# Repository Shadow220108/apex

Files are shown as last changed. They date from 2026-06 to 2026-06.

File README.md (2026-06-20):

<h1 align="center">
  <br>
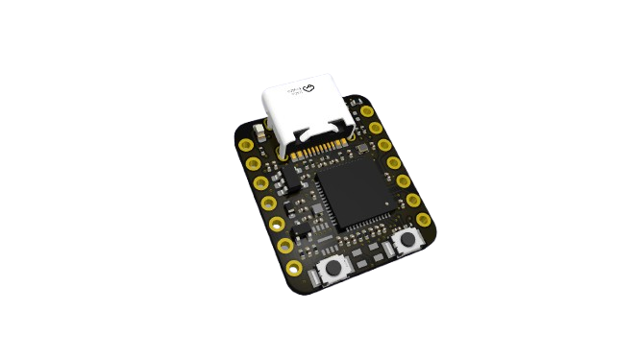
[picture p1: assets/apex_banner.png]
apex banner
  

  <br>
  Apex
  <br>
</h1>
<h3 align="center">
A fully open-sourced compact devboard inspired by the Seed Studio Xiao RP2040 with extra features such as LiPo support 
</h3>

| Front Render | Back Render | 
| --- | --- |
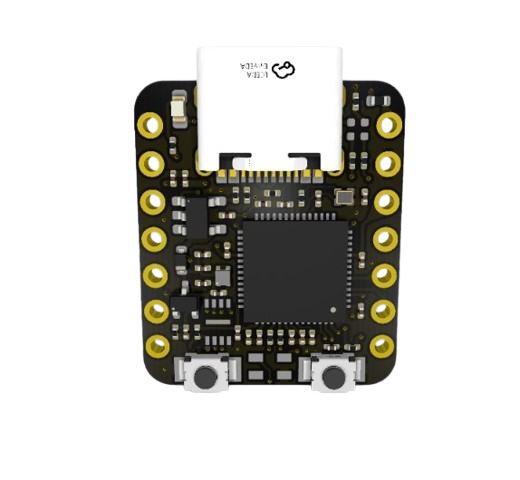
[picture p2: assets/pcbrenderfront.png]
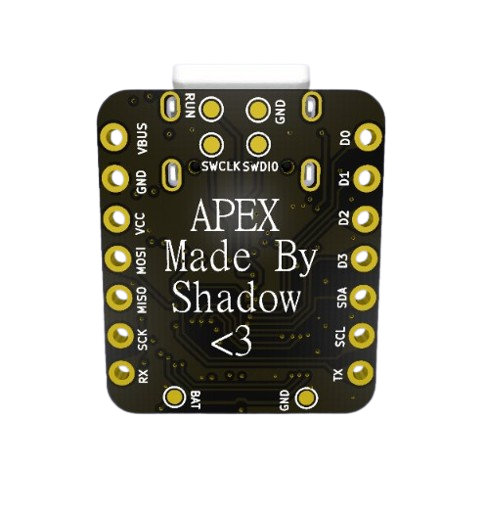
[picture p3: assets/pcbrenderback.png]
|  |  | 

| Zine |
| --- |
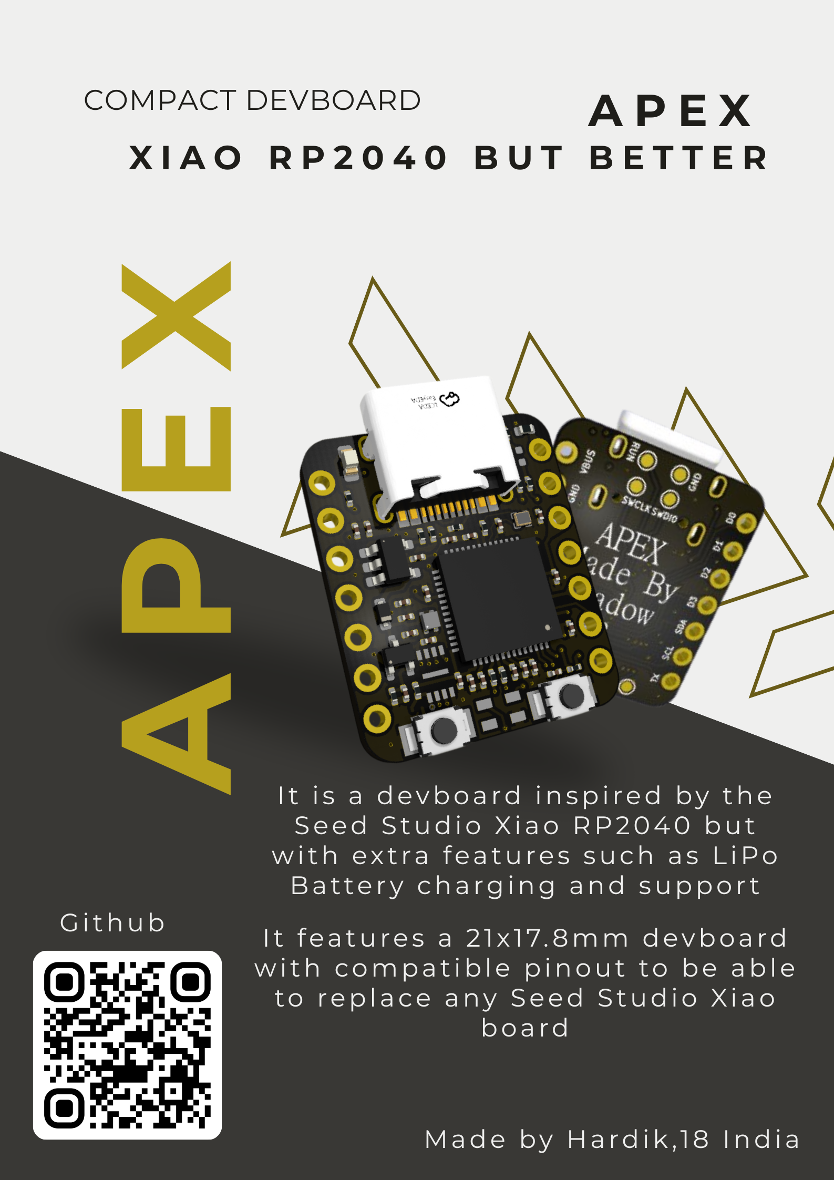
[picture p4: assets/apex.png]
|  |

## Features
- **RP2040 MCU** - Dual ARM Cortex-M0+ @ 133MHz MCU.
- **Very compact, XIAO SEEED inspired formfactor**.
- **4 ADC and 7 digital GPIO pins**.
- **5V and 3.3V power pins**.
- Power indicator LED, addressable LED and another RGB LED
- LiPo Battery support and charging circuit
- **USB C** - for programming and power.

## PCB Design 
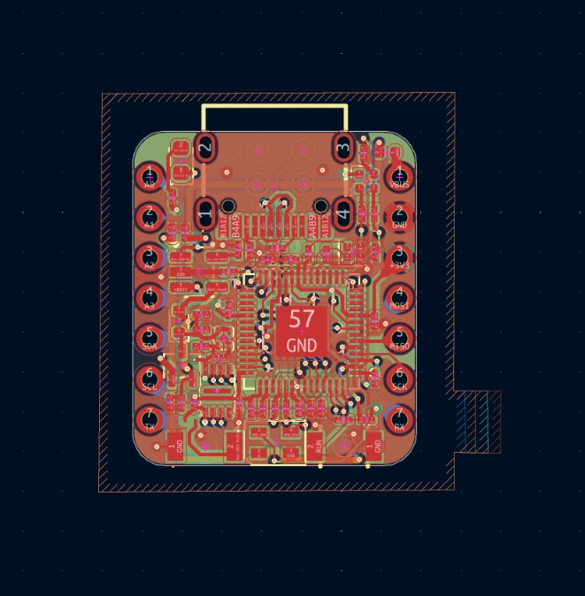
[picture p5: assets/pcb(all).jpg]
|  |
|--- |  

 ### The PCB is 4 layers with dimensions 21x17.8mm, made to be easily replacable to any Xiao board.  

 ### All the PCB files are [here](https://github.com/Shadow220108/apex/blob/main/PCB) 

| Front Layer | Inner Layer 1 |
| --- | --- |
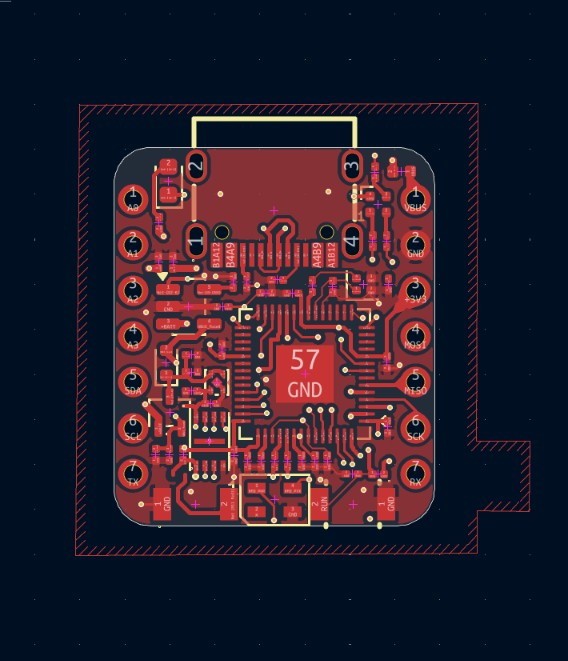
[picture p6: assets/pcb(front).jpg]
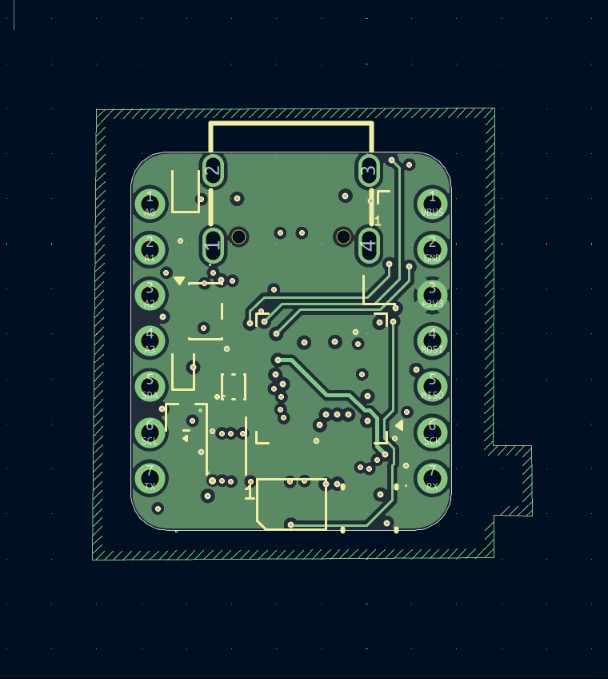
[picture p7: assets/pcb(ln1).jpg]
|  |  |
| Inner Layer 2 | Bottom layer |
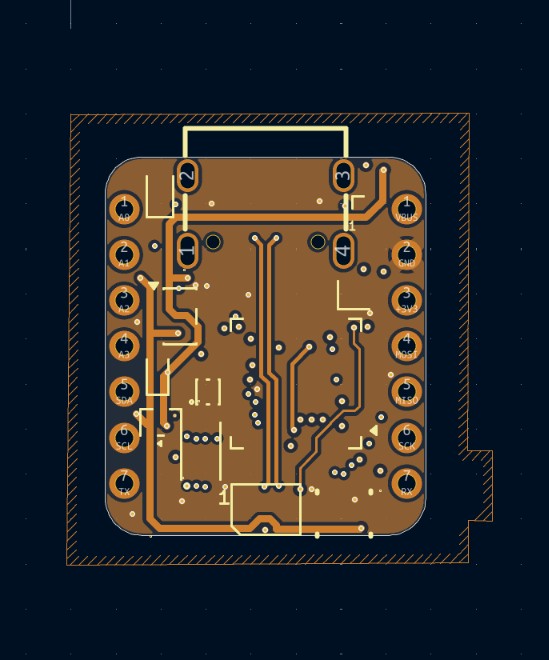
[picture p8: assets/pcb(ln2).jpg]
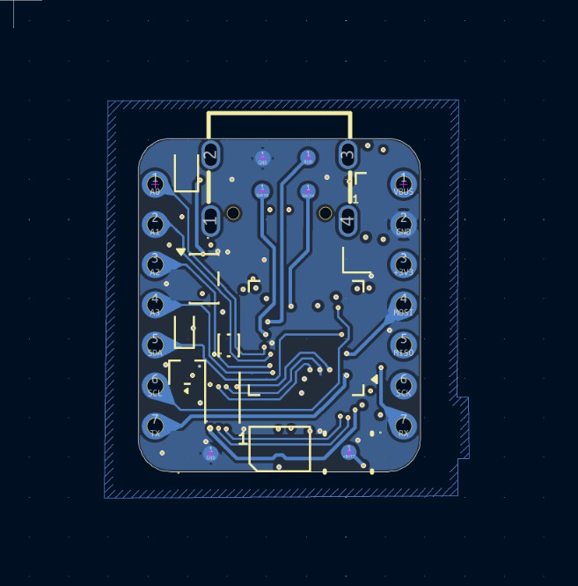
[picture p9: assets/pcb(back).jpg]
|  |  |

## Schematics  

Here are the schematic designs,

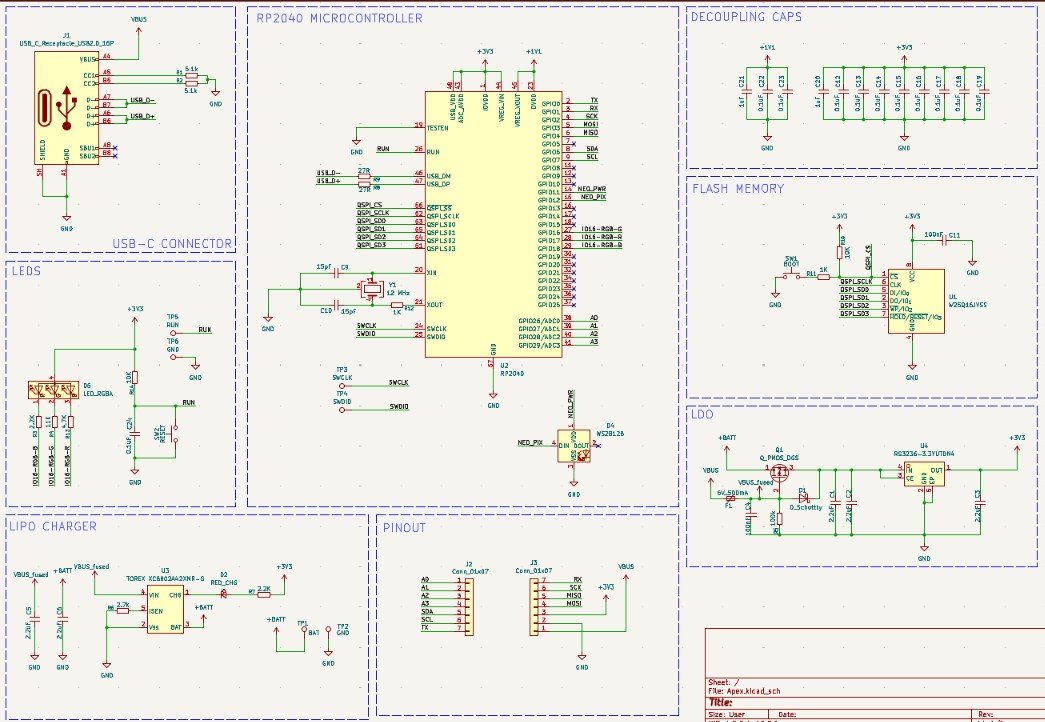
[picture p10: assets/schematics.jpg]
|  |
| --- |  

## Pinout  

This is a general pinout 

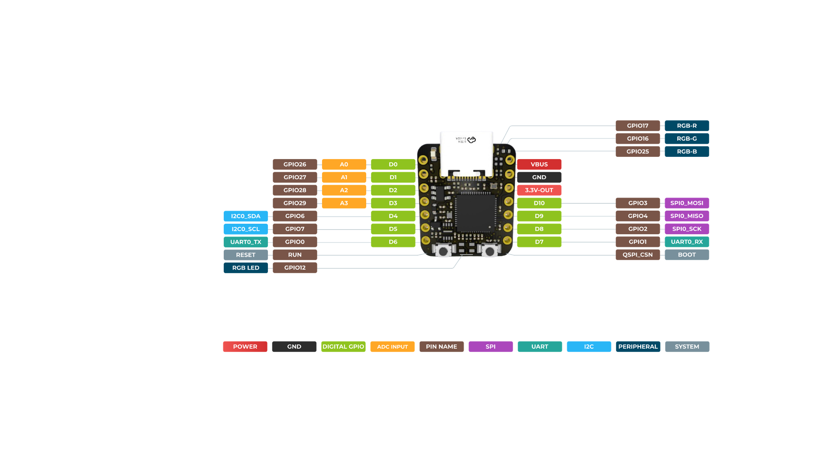
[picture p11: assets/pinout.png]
|  | 
| --- | 

( Credits to the Seed Studio for making this, since my board is inspired on the Xiao, I have used the pinout provided by them ) 

## Why was it made?  

While using the Seed Studio Xiao RP2040 for one of my projects, I realised it doesn't have LiPo support   
and I couldn't use it, unfortunately I had to use a different MCU then, but now I designed one with  
the simplicity of RP2040 with being able to charge LiPo 

## How you can get one for yourself? 

That is pretty easy, you have all the files you will need in the production folder, order the development  
board from any PCB fab ( I chose JLC cause its cheap and has good quality ) and BINGO! You will have it  
to use for any purpose you want!  

## How do you use it?  
You can use it as any normal RP2040 Devboard, enter the boootloader mode  
by holding the BOOT buttom while connecting to your device, flash it with  
firmware and you are good to go!  I have attached a simple code to blink the LED  
available on the board.  

## BOM  
|Name|Purpose |Quantity|Total Cost (USD)|Link |Distributor|
|----|---|---|---|---|---|
|PCBA|Development Board|2 |79.03 |https://jlcpcb.com/|JLCPCB |
| | | Total | 79.03 | 

LCSC BOM for the components on board is [here](https://github.com/Shadow220108/apex/blob/main/production/apex_bom.csv)

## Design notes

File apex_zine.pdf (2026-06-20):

## X I A O R P 2 0 4 0 B U T B E T T E R

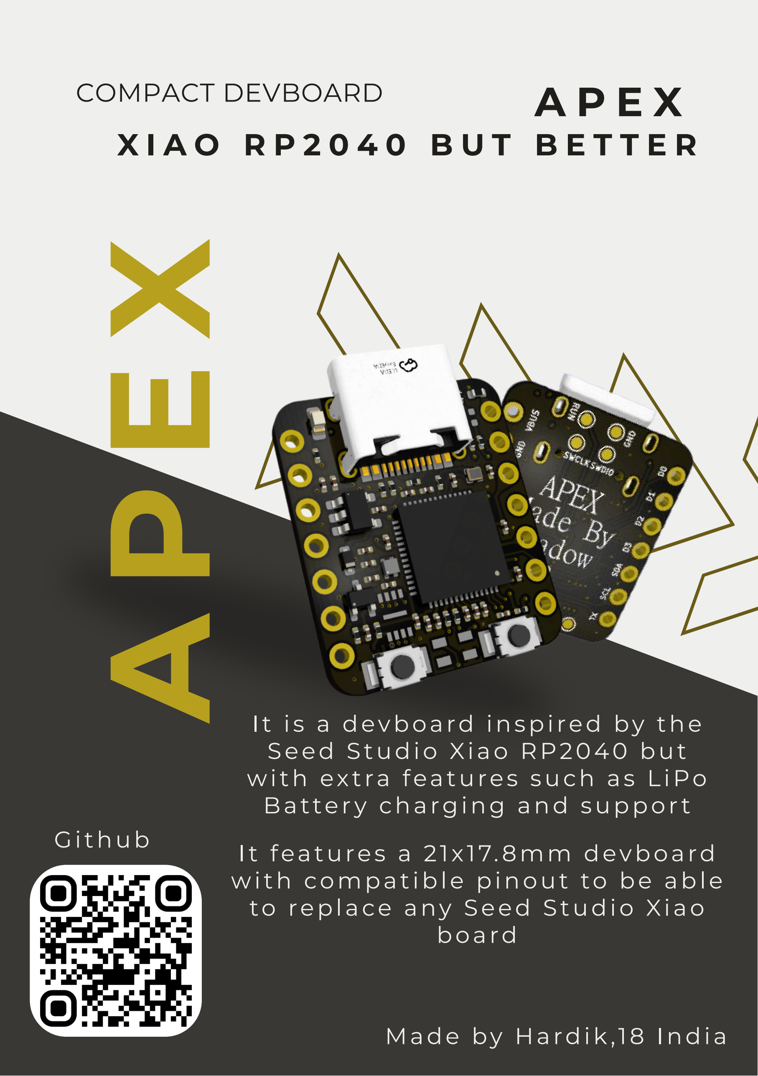
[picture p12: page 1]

A

P

E

X

I t i s a devboard inspi red by the Seed Studio Xiao RP2040 but wi th ex t ra features such as LiPo Bat ter y charging and suppor t

Made by H ardik,18 India

COMPACT DEVBOARD | A P E X

I t features a 21 x 17.8mm devboard wi th compat ible pinout to be able to replace any Seed Studio Xiao board

Gi thub

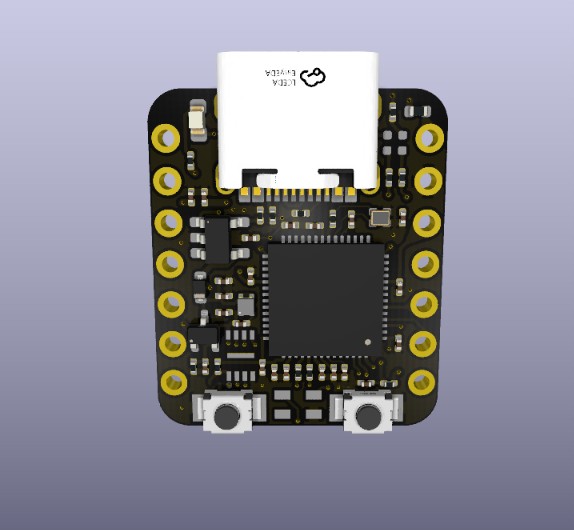
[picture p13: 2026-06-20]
assets/pcbrenderfront.jpg

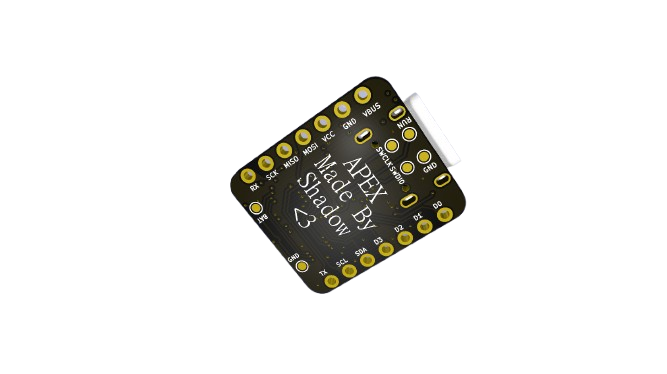
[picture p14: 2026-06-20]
assets/apex_back.png

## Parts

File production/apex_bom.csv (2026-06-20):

Designator | Footprint | Quantity | Value | LCSC Part #
C1, C2, C3, C5, C6 | 0201 | 5 | 2.2uF
C10, C9 | 0201 | 2 | 15pF
C11, C4 | 0201 | 2 | 100nF
C12, C13, C14, C15, C16, C17, C18, C19, C22, C23, C24 | 0201 | 11 | 0.1uF
C20, C21 | 0201 | 2 | 1uF
D1 | D_SOD-523 | 1 | D_Schottky
D2 | 0603 | 1 | RED_CHG
D4 | LED_SK6805_PLCC4_2.4x2.7mm_P1.3mm | 1 | WS2812B
D5 | LED_SK6812_EC15_1.5x1.5mm | 1 | LED_RGBA
F1 | 0402 | 1 | 6V_500mA
J1 | USB-C_SMD-TYPE-C-31-M-12_1 | 1 | USB_C_Receptacle_USB2.0_16P | C165948
J2, J3 | PinHeader_1x07_P2.54mm_Vertical | 2 | Conn_01x07
Q1 | SOT-323_SC-70 | 1 | Q_PMOS_DGS
R1, R2 | 0201 | 2 | 5.1k
R10, R14 | 0201 | 2 | 10K
R12 | 0201 | 1 | 1K
R13 | 0201 | 1 | 4.7K
R3, R7 | 0201 | 2 | 2.2K
R4 | 0201 | 1 | 11K
R5 | 0201 | 1 | 100k
R6 | 0201 | 1 | 2.7k
R8, R9 | 0201 | 2 | 27R
SW1 | KEY-SMD_L3.0-W2.5-LS4.0_TD-1183SN | 1 | BOOT | C2905192
SW2 | KEY-SMD_L3.0-W2.5-LS4.0_TD-1183SN | 1 | RESET | C2905192
TP1 | TestPoint_Pad_D1.0mm | 1 | BAT
TP2, TP6 | TestPoint_Pad_D1.0mm | 2 | GND
TP3 | TestPoint_Pad_D1.0mm | 1 | SWCLK
TP4 | TestPoint_Pad_D1.0mm | 1 | SWDI0
TP5 | TestPoint_Pad_D1.0mm | 1 | RUN
U1 | USON-8_L3.0-W2.0-P0.50-BL-EP-1 | 1 | W25Q16JVSS | C2973793
U2 | QFN-56-1EP_7x7mm_P0.4mm_EP3.2x3.2mm | 1 | RP2040
U3 | SOT-23-5 | 1 | TOREX XC6802A42XMR-G
U4 | XDFN-4_L1.0-W1.0-P0.65-BL-EP | 1 | RS3236-3.3YUTDN4 | C379350
Y1 | Crystal_SMD_1210-4Pin_1.2x1.0mm | 1 | 12 MHz

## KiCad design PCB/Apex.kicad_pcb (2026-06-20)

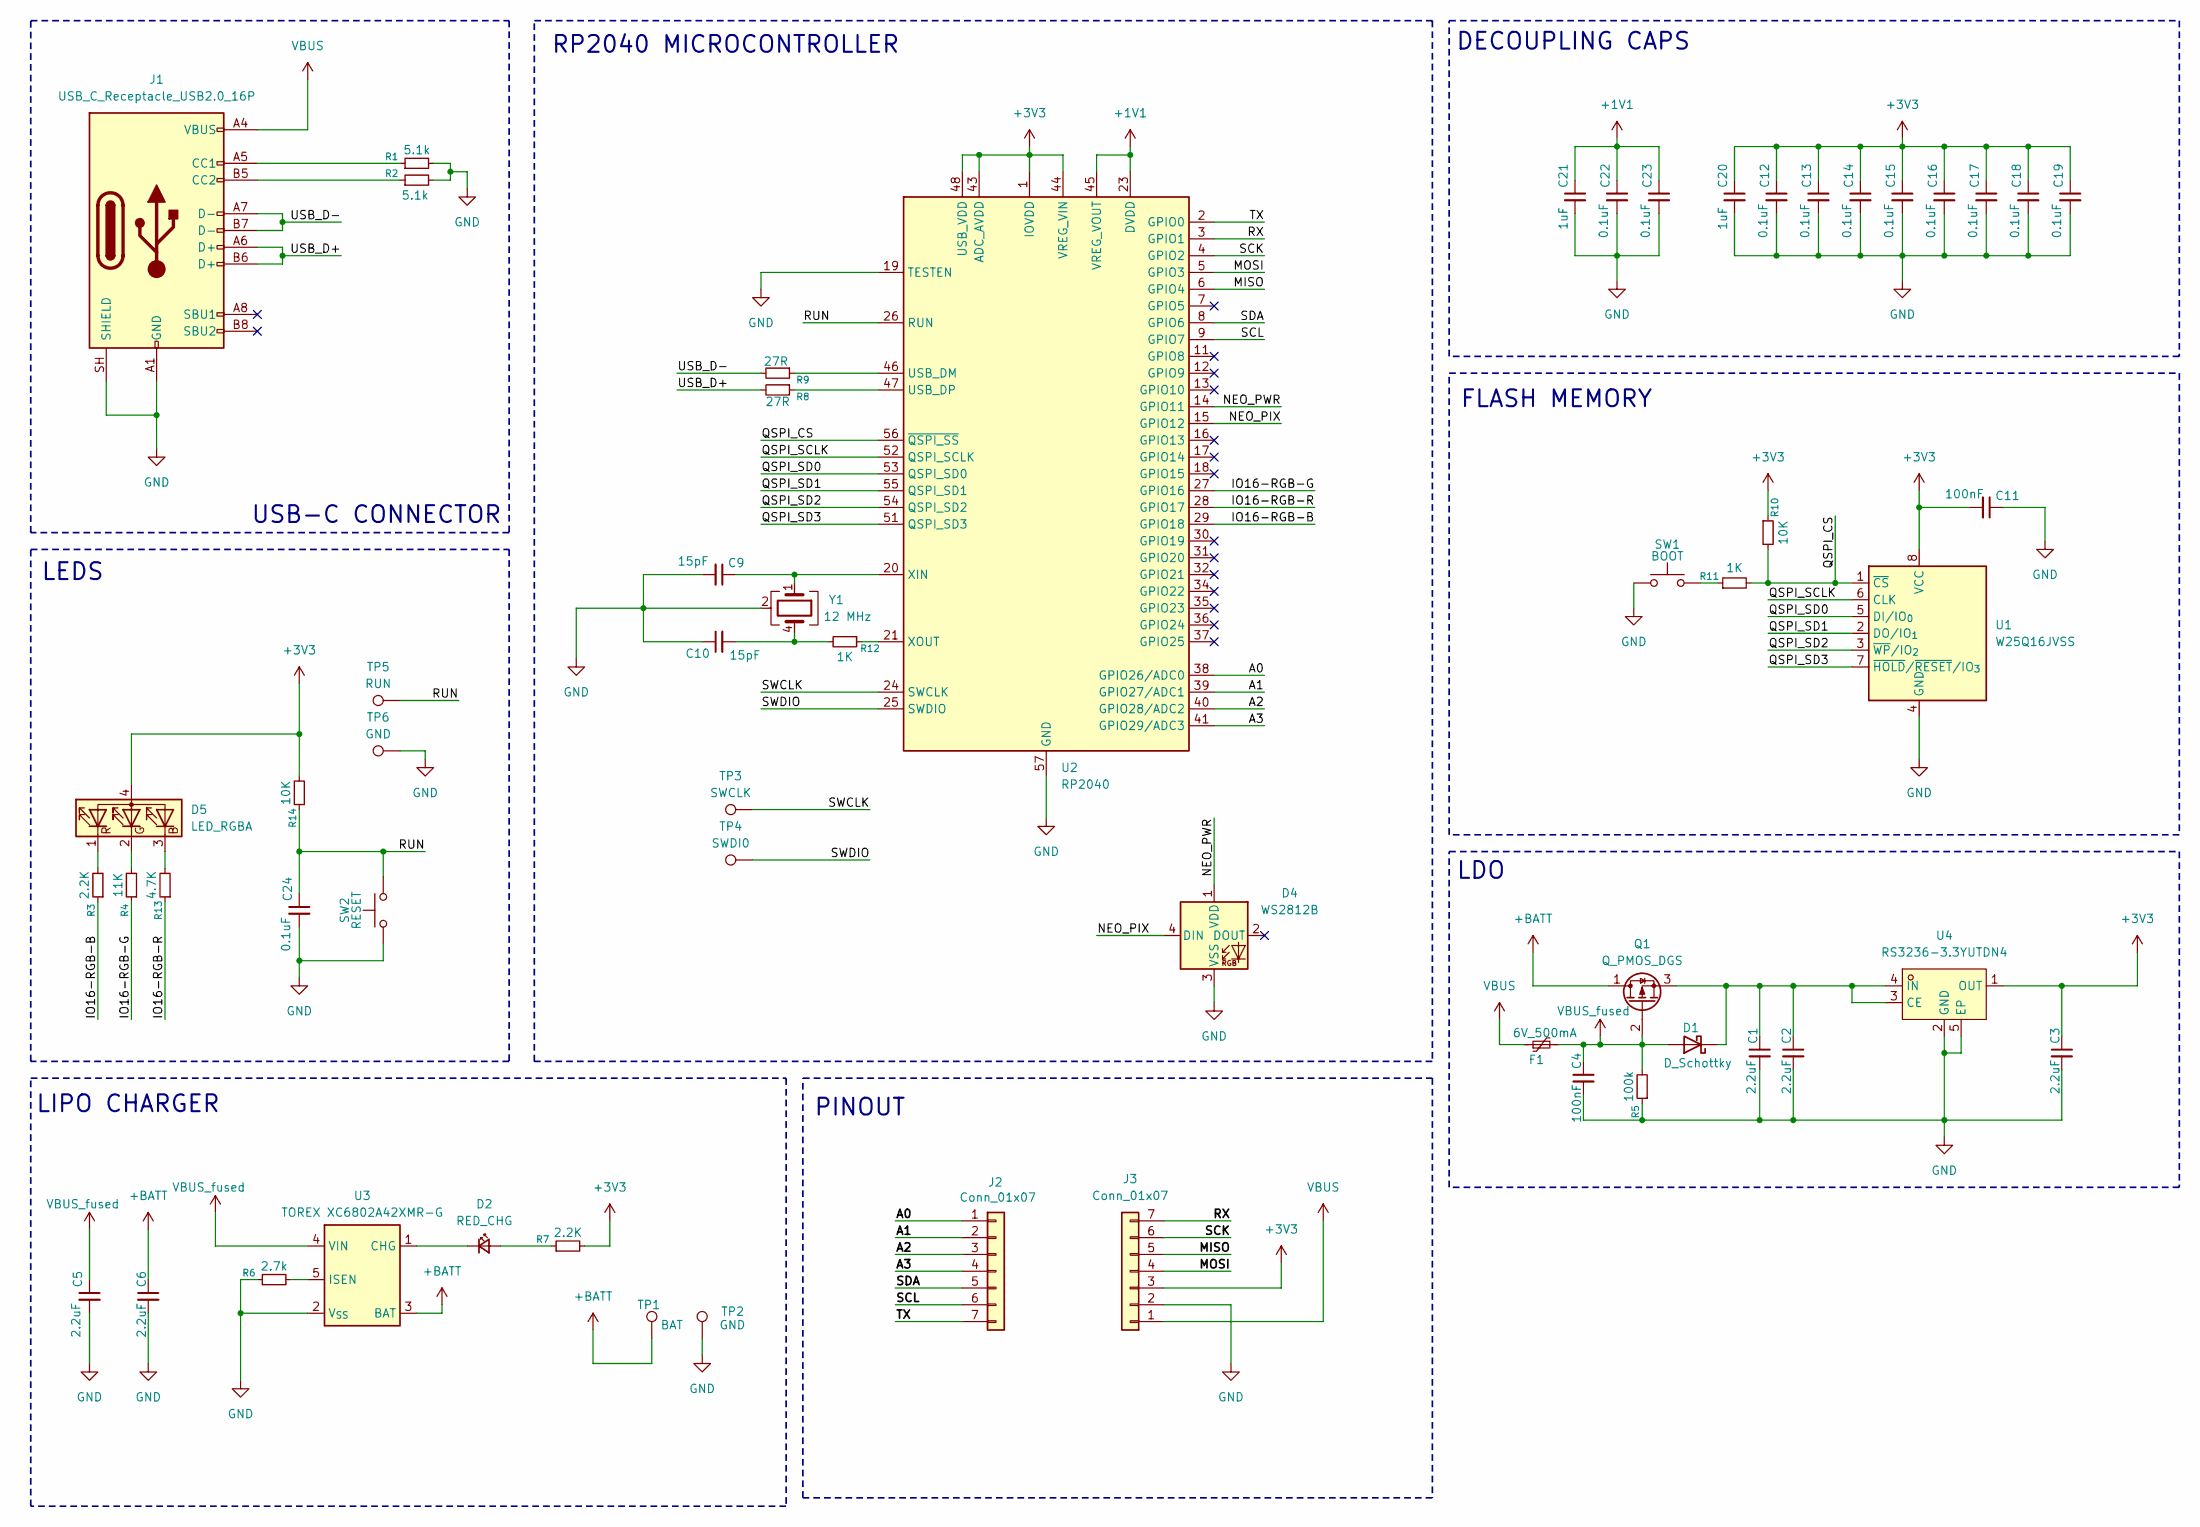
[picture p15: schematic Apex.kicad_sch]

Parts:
C1, C2, C3, C5, C6: 2.2uF; C_0201_0603Metric
C4, C11: 100nF; C_0201_0603Metric
C9, C10: 15pF; C_0201_0603Metric
C12, C13, C14, C15, C16, C17, C18, C19, C22, C23, C24: 0.1uF; C_0201_0603Metric
C20, C21: 1uF; C_0201_0603Metric
D1: D_Schottky; D_SOD-523
D2: RED_CHG; LED_0603_1608Metric
D4: WS2812B; LED_SK6805_PLCC4_2.4x2.7mm_P1.3mm
D5: LED_RGBA; LED_SK6812_EC15_1.5x1.5mm
F1: 6V_500mA; Fuse_0402_1005Metric
J1: USB_C_Receptacle_USB2.0_16P; USB-C_SMD-TYPE-C-31-M-12_1
J2, J3: Conn_01x07; PinHeader_1x07_P2.54mm_Vertical
Q1: Q_PMOS_DGS; SOT-323_SC-70
R1, R2: 5.1k; R_0201_0603Metric
R3, R7: 2.2K; R_0201_0603Metric
R4: 11K; R_0201_0603Metric
R5: 100k; R_0201_0603Metric
R6: 2.7k; R_0201_0603Metric
R8, R9: 27R; R_0201_0603Metric
R10, R14: 10K; R_0201_0603Metric
R11, R12: 1K; R_0201_0603Metric
R13: 4.7K; R_0201_0603Metric
SW1: BOOT; KEY-SMD_L3.0-W2.5-LS4.0_TD-1183SN
SW2: RESET; KEY-SMD_L3.0-W2.5-LS4.0_TD-1183SN
TP1: BAT; TestPoint_Pad_D1.0mm
TP2, TP6: GND; TestPoint_Pad_D1.0mm
TP3: SWCLK; TestPoint_Pad_D1.0mm
TP4: SWDI0; TestPoint_Pad_D1.0mm
TP5: RUN; TestPoint_Pad_D1.0mm
U1: W25Q16JVSS; USON-8_L3.0-W2.0-P0.50-BL-EP-1
U2: RP2040; QFN-56-1EP_7x7mm_P0.4mm_EP3.2x3.2mm
U3: TOREX XC6802A42XMR-G; SOT-23-5
U4: RS3236-3.3YUTDN4; XDFN-4_L1.0-W1.0-P0.65-BL-EP; MPN RS3236-3.3YUTDN4; LCSC Part C379350
Y1: 12 MHz; Crystal_SMD_1210-4Pin_1.2x1.0mm

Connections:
+1V1: C21.1, C22.1, C23.1, U2.23 (DVDD), U2.45 (VREG_VOUT), U2.50 (DVDD)
+3V3: C3.1, C11.2, C12.1, C13.1, C14.1, C15.1, C16.1, C17.1, C18.1, C19.1, C20.1, D5.4 (A), J3.3, R7.2, R10.1, R14.2, U1.8 (VCC), U2.1 (IOVDD), U2.10 (IOVDD), U2.22 (IOVDD), U2.33 (IOVDD), U2.42 (IOVDD), U2.43 (ADC_AVDD), U2.44 (VREG_VIN), U2.48 (USB_VDD), U2.49 (IOVDD), U4.1 (OUT)
+BATT: C6.1, Q1.1 (D), TP1.1 (1_1), U3.3 (BAT)
/A0: J2.1, U2.38 (GPIO26/ADC0)
/A1: J2.2, U2.39 (GPIO27/ADC1)
/A2: J2.3, U2.40 (GPIO28/ADC2)
/A3: J2.4, U2.41 (GPIO29/ADC3)
/IO16-RGB-B: R3.1, U2.29 (GPIO18)
/IO16-RGB-G: R4.1, U2.27 (GPIO16)
/IO16-RGB-R: R13.1, U2.28 (GPIO17)
/MISO: J3.5, U2.6 (GPIO4)
/MOSI: J3.4, U2.5 (GPIO3)
/NEO_PIX: D4.4 (DIN), U2.15 (GPIO12)
/NEO_PWR: D4.1 (VDD), U2.14 (GPIO11)
/QSPI_CS: R10.2, R11.2, U1.1 (~CS), U2.56 (~QSPI_SS)
/QSPI_SCLK: U1.6 (CLK), U2.52 (QSPI_SCLK)
/QSPI_SD0: U1.5 (DI/IO_{0}), U2.53 (QSPI_SD0)
/QSPI_SD1: U1.2 (DO/IO_{1}), U2.55 (QSPI_SD1)
/QSPI_SD2: U1.3 (~WP/IO_{2}), U2.54 (QSPI_SD2)
/QSPI_SD3: U1.7 (~HOLD/~RESET/IO_{3}), U2.51 (QSPI_SD3)
/RUN: C24.1, R14.1, SW2.2, TP5.1 (1_1), U2.26 (RUN)
/RX: J3.7, U2.3 (GPIO1)
/SCK: J3.6, U2.4 (GPIO2)
/SCL: J2.6, U2.9 (GPIO7)
/SDA: J2.5, U2.8 (GPIO6)
/SWCLK: TP3.1 (1_1), U2.24 (SWCLK)
/SWDIO: TP4.1 (1_1), U2.25 (SWDIO)
/TX: J2.7, U2.2 (GPIO0)
/USB_D+: J1.A6 (D+), J1.B6 (D+), R8.2
/USB_D-: J1.A7 (D-), J1.B7 (D-), R9.2
GND: C1.2, C2.2, C3.2, C4.2, C5.2, C6.2, C9.2, C10.1, C11.1, C12.2, C13.2, C14.2, C15.2, C16.2, C17.2, C18.2, C19.2, C20.2, C21.2, C22.2, C23.2, C24.2, D4.3 (VSS), J1.A1 (GND), J1.A12 (GND), J1.B1 (GND), J1.B12 (GND), J1.SH (SHIELD), J3.2, R1.2, R2.2, R5.1, R6.1, SW1.1, SW2.1, TP2.1 (1_1), TP6.1 (1_1), U1.4 (GND), U2.19 (TESTEN), U2.57 (GND), U3.2 (V_{SS}), U4.2 (GND), U4.5 (EP), Y1.2 (G), Y1.3 (G)
unnamed: C10.2, R12.2, Y1.4
unnamed: C1.1, C2.1, D1.1 (K), Q1.3 (S), U4.3 (CE), U4.4 (IN)
unnamed: D2.2 (A), R7.1
unnamed: D2.1 (K), U3.1 (CHG)
unnamed: D5.3 (BK), R13.2
unnamed: D5.2 (GK), R4.2
unnamed: D5.1 (RK), R3.2
unnamed: J1.A5 (CC1), R1.1
unnamed: J1.B5 (CC2), R2.1
unnamed: R11.1, SW1.2
unnamed: R9.1, U2.46 (USB_DM)
unnamed: R8.1, U2.47 (USB_DP)
unnamed: C9.1, U2.20 (XIN), Y1.1
unnamed: R12.1, U2.21 (XOUT)
unnamed: R6.2, U3.5 (ISEN)
VBUS: F1.1, J1.A4 (VBUS), J1.A9 (VBUS), J1.B4 (VBUS), J1.B9 (VBUS), J3.1
VBUS_fused: C4.1, C5.1, D1.2 (A), F1.2, Q1.2 (G), R5.2, U3.4 (VIN)

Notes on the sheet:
FLASH MEMORY
LEDS
USB-C CONNECTOR
LIPO CHARGER
LDO
PINOUT
RP2040 MICROCONTROLLER
DECOUPLING CAPS

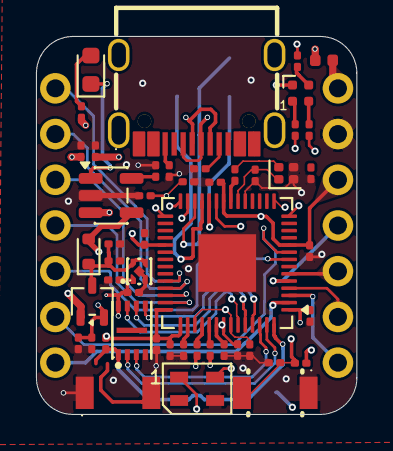
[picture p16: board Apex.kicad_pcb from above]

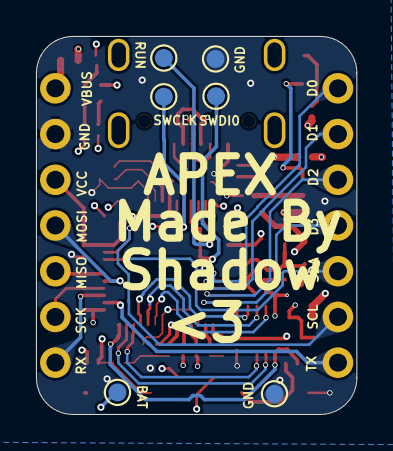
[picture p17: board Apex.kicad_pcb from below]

Board: 4 copper layers, 17.8 x 21.0 mm, 57 parts (8 on the bottom side), 47 nets.

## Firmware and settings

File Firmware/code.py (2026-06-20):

import time
import board
import digitalio

# Setup the blue user LED (You can change this to board.LED_GREEN or board.LED_RED)
led = digitalio.DigitalInOut(board.LED_BLUE)
led.direction = digitalio.Direction.OUTPUT

while True:
    led.value = False  # Turn LED ON (Active Low)
    time.sleep(0.5)    # Wait half a second
    led.value = True   # Turn LED OFF
    time.sleep(0.5)    # Wait half a second
